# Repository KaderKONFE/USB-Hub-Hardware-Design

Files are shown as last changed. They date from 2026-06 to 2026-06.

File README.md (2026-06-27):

# USB Hub Hardware & PCB Design

This repository contains the schematic and PCB design for a high-speed USB Hub, developed according to industrial design rules and signal integrity standards.

## Tech Stack & Tools
* **CAD Software:** KiCad
* **Design Type:** Schematic Capture & PCB Layout
* **Key Focus:** Signal integrity, power management, and protection circuits.

## Features
* Designed high-speed USB data lines with proper impedance matching.
* Integrated power management and circuit protection elements.

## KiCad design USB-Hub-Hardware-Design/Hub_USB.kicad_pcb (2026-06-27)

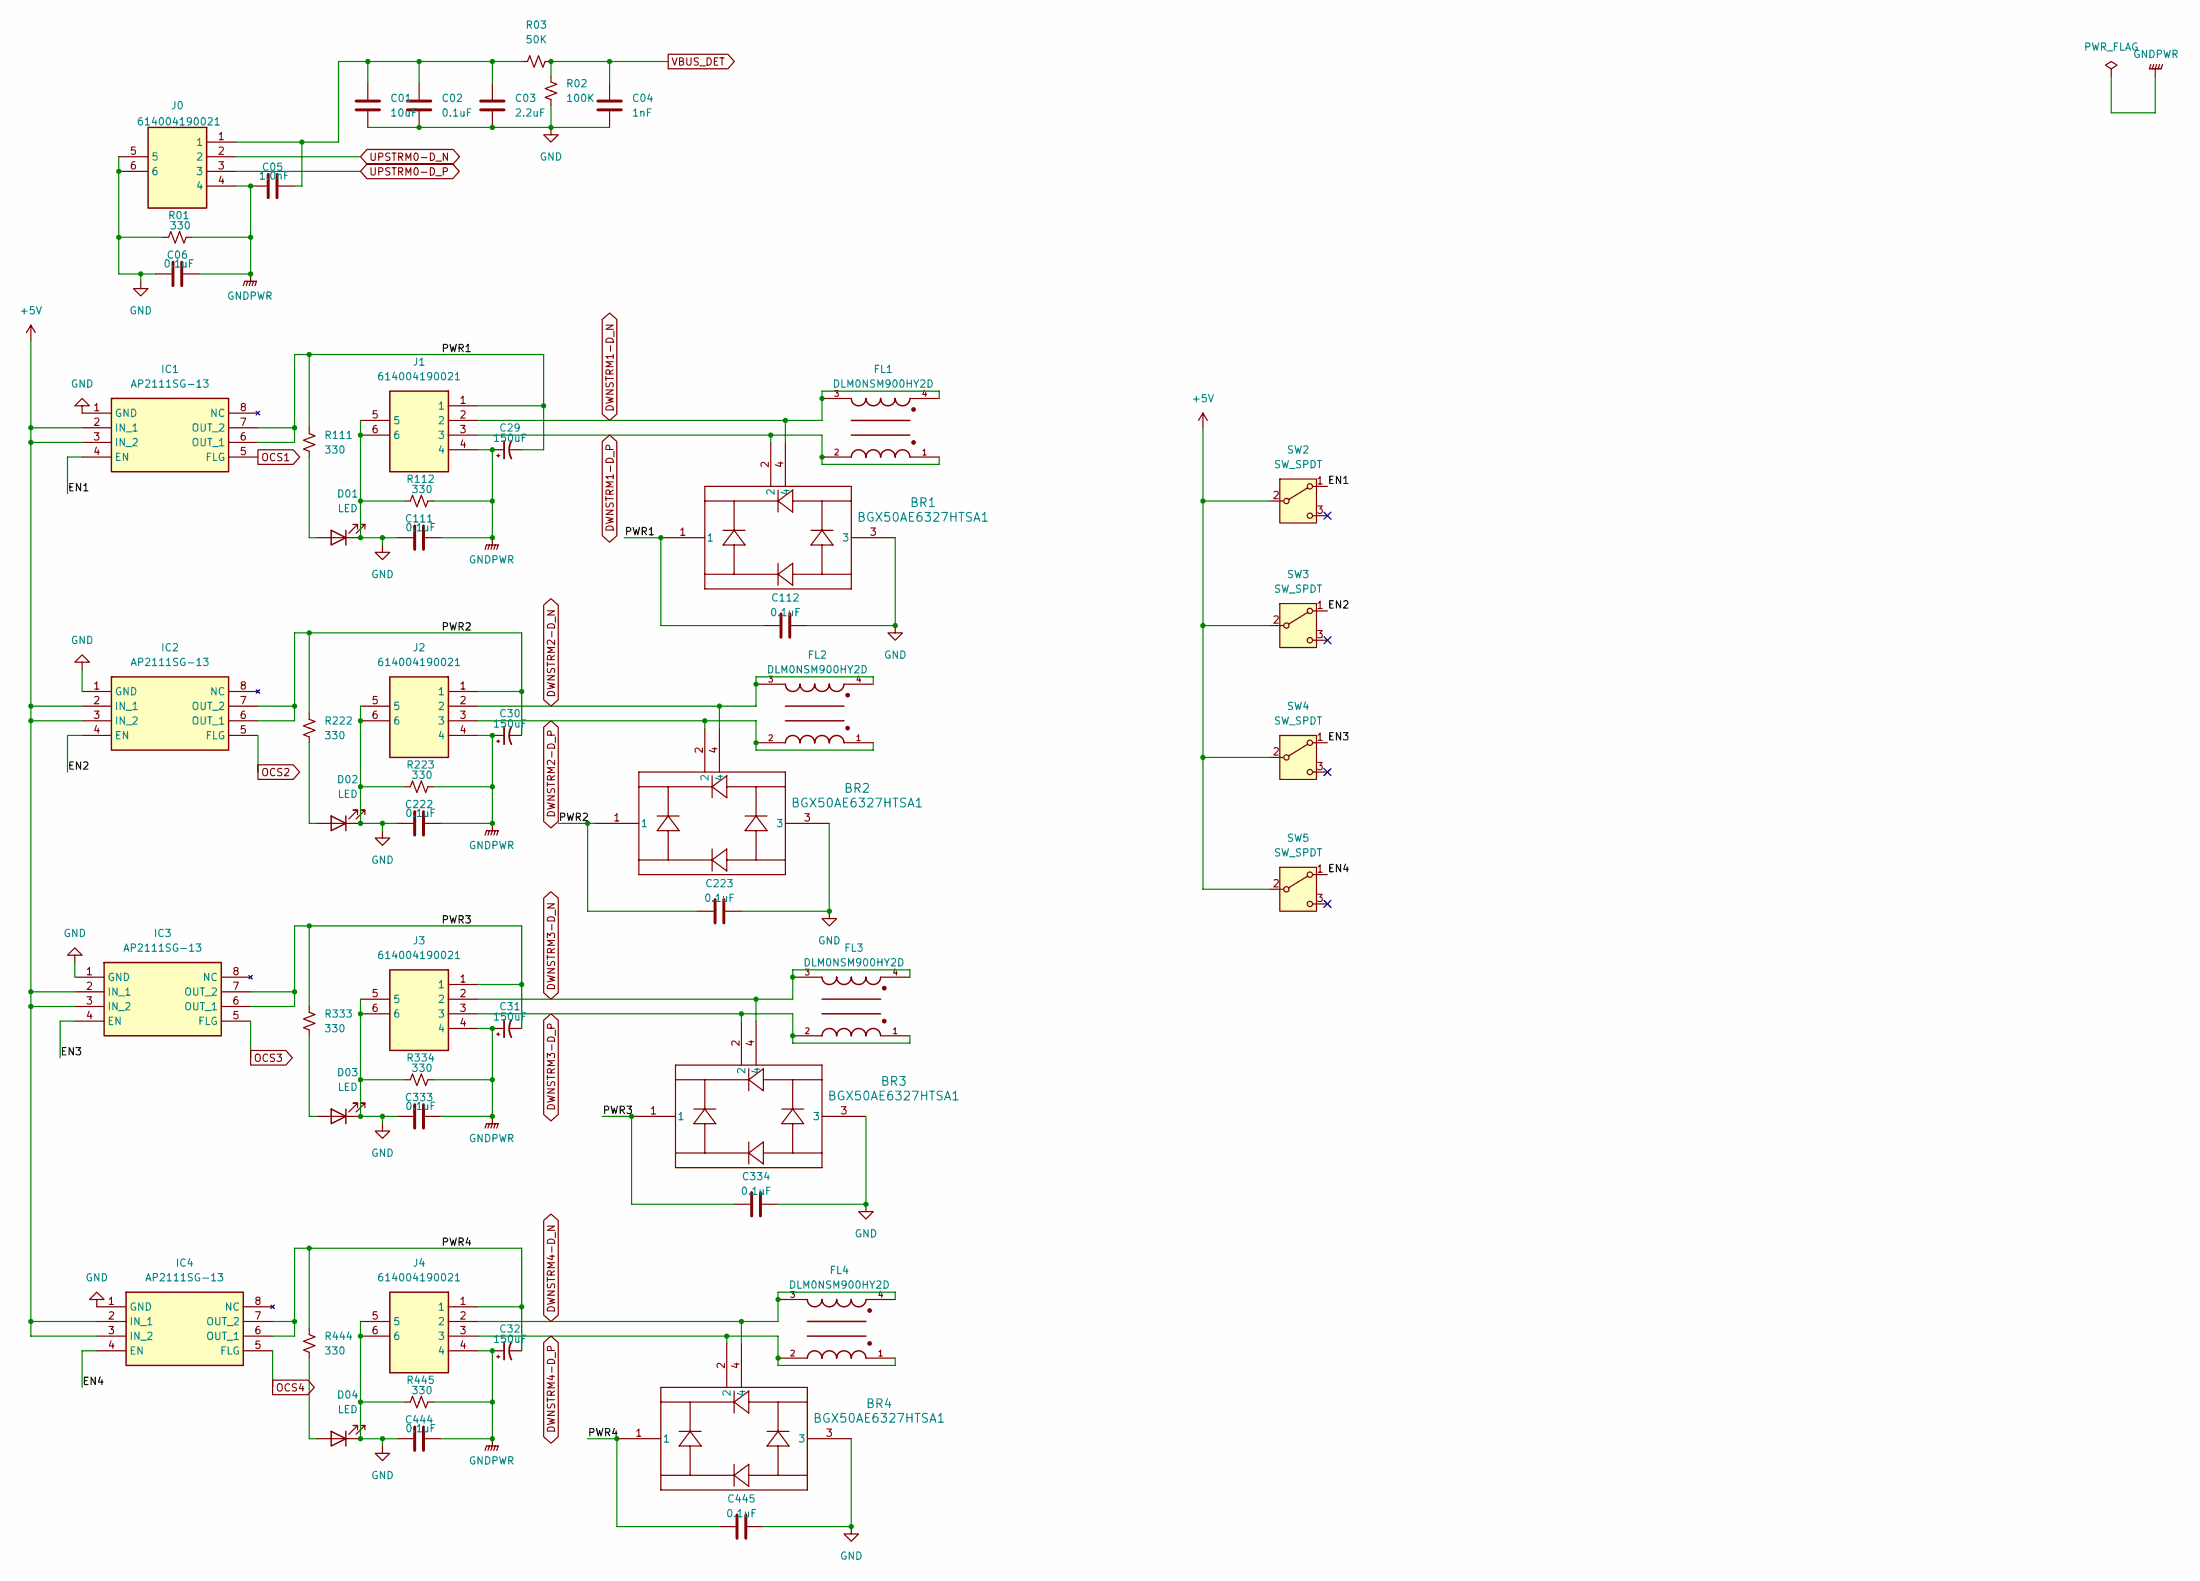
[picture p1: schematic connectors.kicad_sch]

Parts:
BR1, BR2, BR3, BR4: BGX50AE6327HTSA1
C01: 10uF; C_0603_1608Metric_Pad1.08x0.95mm_HandSolder
C02, C06, C111, C112, C222, C223, C333, C334, C444, C445: 0.1uF; C_0603_1608Metric_Pad1.08x0.95mm_HandSolder
C03: 2.2uF; C_0603_1608Metric_Pad1.08x0.95mm_HandSolder
C04: 1nF; C_0603_1608Metric_Pad1.08x0.95mm_HandSolder
C05: 1.0nF; C_0603_1608Metric_Pad1.08x0.95mm_HandSolder
C29, C30, C31, C32: 150uF; CP_Elec_5x5.7
D01, D02, D03, D04: LED; LED_0201_0603Metric_Pad0.64x0.40mm_HandSolder
FL1, FL2, FL3, FL4: DLM0NSM900HY2D; PARTREV N/A
IC1, IC2, IC3, IC4: AP2111SG-13; Manufacturer_Part_Number AP2111SG-13; Mouser Part Number 621-AP2111SG-13
J0, J1, J2, J3, J4: 614004190021; Manufacturer_Part_Number 614004190021; Mouser Part Number 710-614004190021
R01, R111, R112, R222, R223, R333, R334, R444, R445: 330; R_0603_1608Metric_Pad0.98x0.95mm_HandSolder
R02: 100K; R_0603_1608Metric_Pad0.98x0.95mm_HandSolder
R03: 50K; R_0603_1608Metric_Pad0.98x0.95mm_HandSolder
SW2, SW3, SW4, SW5: SW_SPDT; SW_SPDT_REED_MSDM-DT

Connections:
+5V: IC1.2 (IN_1), IC1.3 (IN_2), IC2.2 (IN_1), IC2.3 (IN_2), IC3.2 (IN_1), IC3.3 (IN_2), IC4.2 (IN_1), IC4.3 (IN_2), SW2.2 (B), SW3.2 (B), SW4.2 (B), SW5.2 (B); also elsewhere on the board
/Connectors/EN1: IC1.4 (EN), SW2.1 (A)
/Connectors/EN2: IC2.4 (EN), SW3.1 (A)
/Connectors/EN3: IC3.4 (EN), SW4.1 (A)
/Connectors/EN4: IC4.4 (EN), SW5.1 (A)
/Connectors/PWR1: BR1.1, C29.2, C112.2, IC1.6 (OUT_1), IC1.7 (OUT_2), J1.1, R111.1
/Connectors/PWR2: BR2.1, C30.2, C223.2, IC2.6 (OUT_1), IC2.7 (OUT_2), J2.1, R222.1
/Connectors/PWR3: BR3.1, C31.2, C334.2, IC3.6 (OUT_1), IC3.7 (OUT_2), J3.1, R333.1
/Connectors/PWR4: BR4.1, C32.2, C445.2, IC4.6 (OUT_1), IC4.7 (OUT_2), J4.1, R444.1
DWNSTRM1-D_N: BR1.4, FL1.3, FL1.4, J1.2; also elsewhere on the board
DWNSTRM1-D_P: BR1.2, FL1.1, FL1.2, J1.3; also elsewhere on the board
DWNSTRM2-D_N: BR2.4, FL2.3, FL2.4, J2.2; also elsewhere on the board
DWNSTRM2-D_P: BR2.2, FL2.1, FL2.2, J2.3; also elsewhere on the board
DWNSTRM3-D_N: BR3.4, FL3.3, FL3.4, J3.2; also elsewhere on the board
DWNSTRM3-D_P: BR3.2, FL3.1, FL3.2, J3.3; also elsewhere on the board
DWNSTRM4-D_N: BR4.4, FL4.3, FL4.4, J4.2; also elsewhere on the board
DWNSTRM4-D_P: BR4.2, FL4.1, FL4.2, J4.3; also elsewhere on the board
GND: BR1.3, BR2.3, BR3.3, BR4.3, C01.2, C02.2, C03.2, C04.2, C06.1, C111.1, C112.1, C222.1, C223.1, C333.1, C334.1, C444.1, C445.1, D01.1 (K), D02.1 (K), D03.1 (K), D04.1 (K), IC1.1 (GND), IC2.1 (GND), IC3.1 (GND), IC4.1 (GND), J0.5, J0.6, J1.5, J1.6, J2.5, J2.6, J3.5, J3.6, J4.5, J4.6, R01.1, R02.1, R112.1, R223.1, R334.1, R445.1; also elsewhere on the board
GNDPWR: C05.1, C06.2, C29.1, C30.1, C31.1, C32.1, C111.2, C222.2, C333.2, C444.2, J0.4, J1.4, J2.4, J3.4, J4.4, R01.2, R112.2, R223.2, R334.2, R445.2
unnamed: C01.1, C02.1, C03.1, C05.2, J0.1, R03.1
unnamed: D01.2 (A), R111.2
unnamed: D02.2 (A), R222.2
unnamed: D03.2 (A), R333.2
unnamed: D04.2 (A), R444.2
OCS1: IC1.5 (FLG); also elsewhere on the board
OCS2: IC2.5 (FLG); also elsewhere on the board
OCS3: IC3.5 (FLG); also elsewhere on the board
OCS4: IC4.5 (FLG); also elsewhere on the board
UPSTRM0-D_N: J0.2; also elsewhere on the board
UPSTRM0-D_P: J0.3; also elsewhere on the board
VBUS_DET: C04.1, R02.2, R03.2; also elsewhere on the board

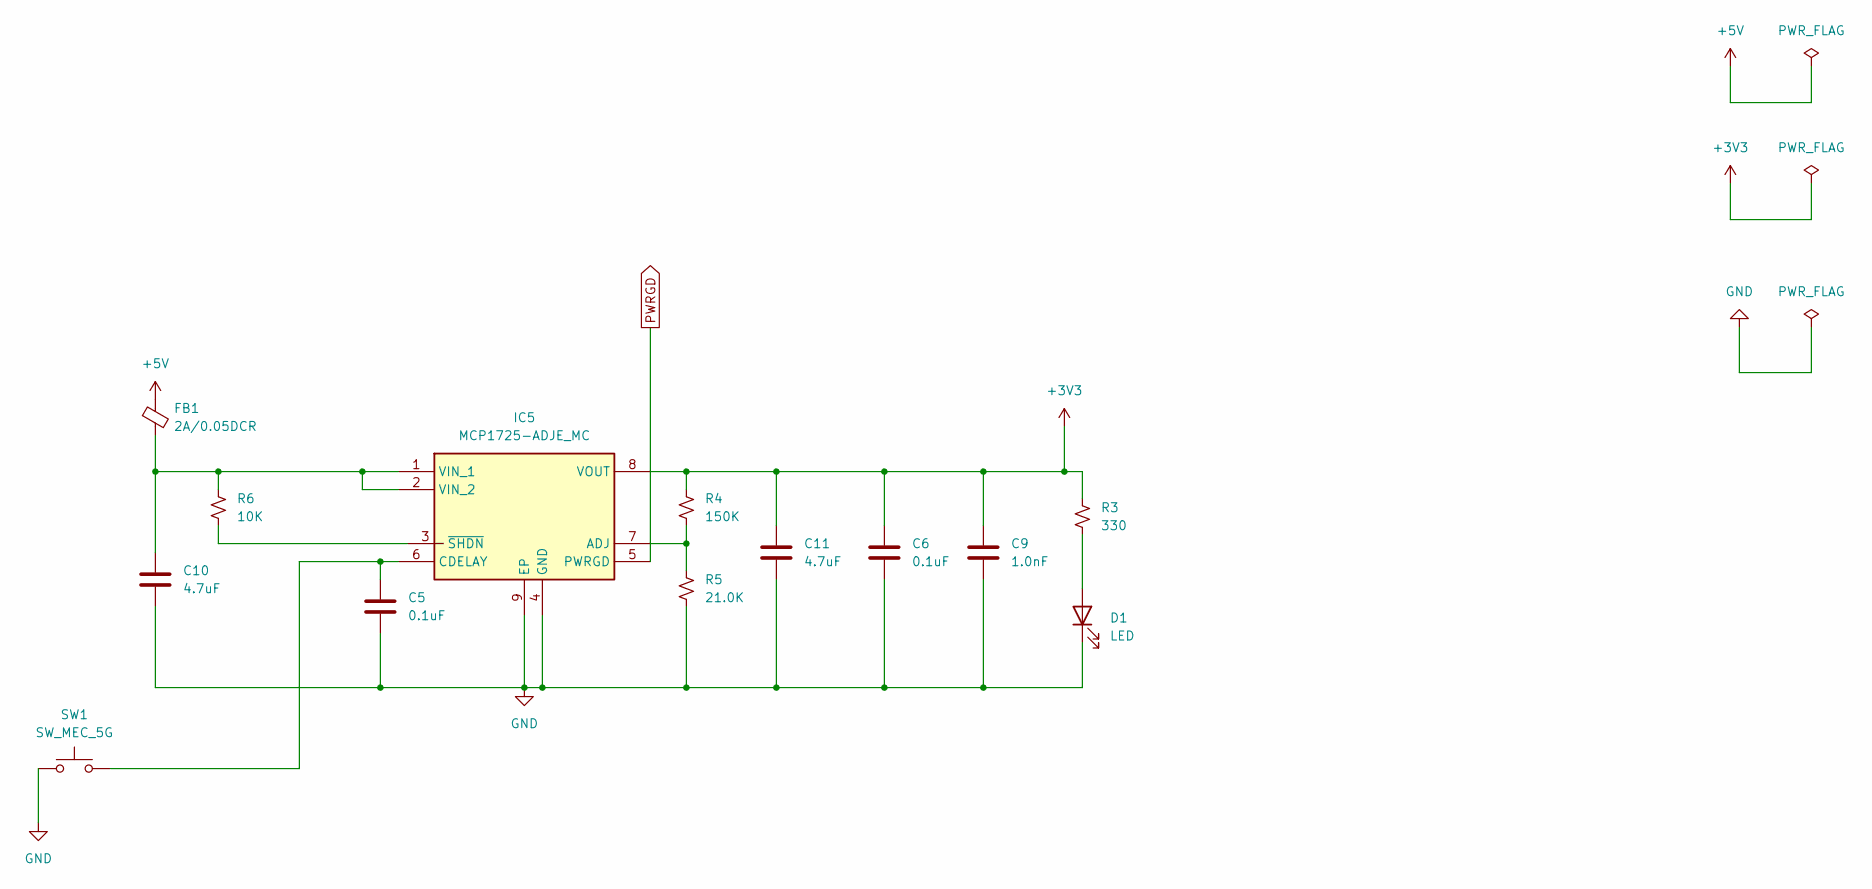
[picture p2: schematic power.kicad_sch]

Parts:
C5, C6: 0.1uF; C_0603_1608Metric_Pad1.08x0.95mm_HandSolder
C9: 1.0nF; C_0603_1608Metric_Pad1.08x0.95mm_HandSolder
C10, C11: 4.7uF; C_0603_1608Metric_Pad1.08x0.95mm_HandSolder
D1: LED; LED_0201_0603Metric_Pad0.64x0.40mm_HandSolder
FB1: 2A/0.05DCR; L_Vishay_IHSM-3825
IC5: MCP1725-ADJE_MC; Manufacturer_Part_Number MCP1725-ADJE/MC; Mouser Part Number 579-MCP1725-ADJE/MC
R3: 330; R_0603_1608Metric_Pad0.98x0.95mm_HandSolder
R4: 150K; R_0603_1608Metric_Pad0.98x0.95mm_HandSolder
R5: 21.0K; R_0603_1608Metric_Pad0.98x0.95mm_HandSolder
R6: 10K; R_0603_1608Metric_Pad0.98x0.95mm_HandSolder
SW1: SW_MEC_5G; SW_MEC_5GSH9

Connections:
+3V3: C6.1, C9.1, C11.1, IC5.8 (VOUT), R3.1, R4.1; also elsewhere on the board
+5V: FB1.1; also elsewhere on the board
GND: C5.2, C6.2, C9.2, C10.2, C11.2, D1.1 (K), IC5.4 (GND), IC5.9 (EP), R5.2, SW1.1 (A), SW1.2 (A); also elsewhere on the board
unnamed: D1.2 (A), R3.2
unnamed: IC5.7 (ADJ), R4.2, R5.1
unnamed: C5.1, IC5.6 (CDELAY), SW1.3 (B), SW1.4 (B)
unnamed: C10.1, FB1.2, IC5.1 (VIN_1), IC5.2 (VIN_2), R6.1
unnamed: IC5.3 (~SHDN), R6.2
PWRGD: IC5.5 (PWRGD); also elsewhere on the board

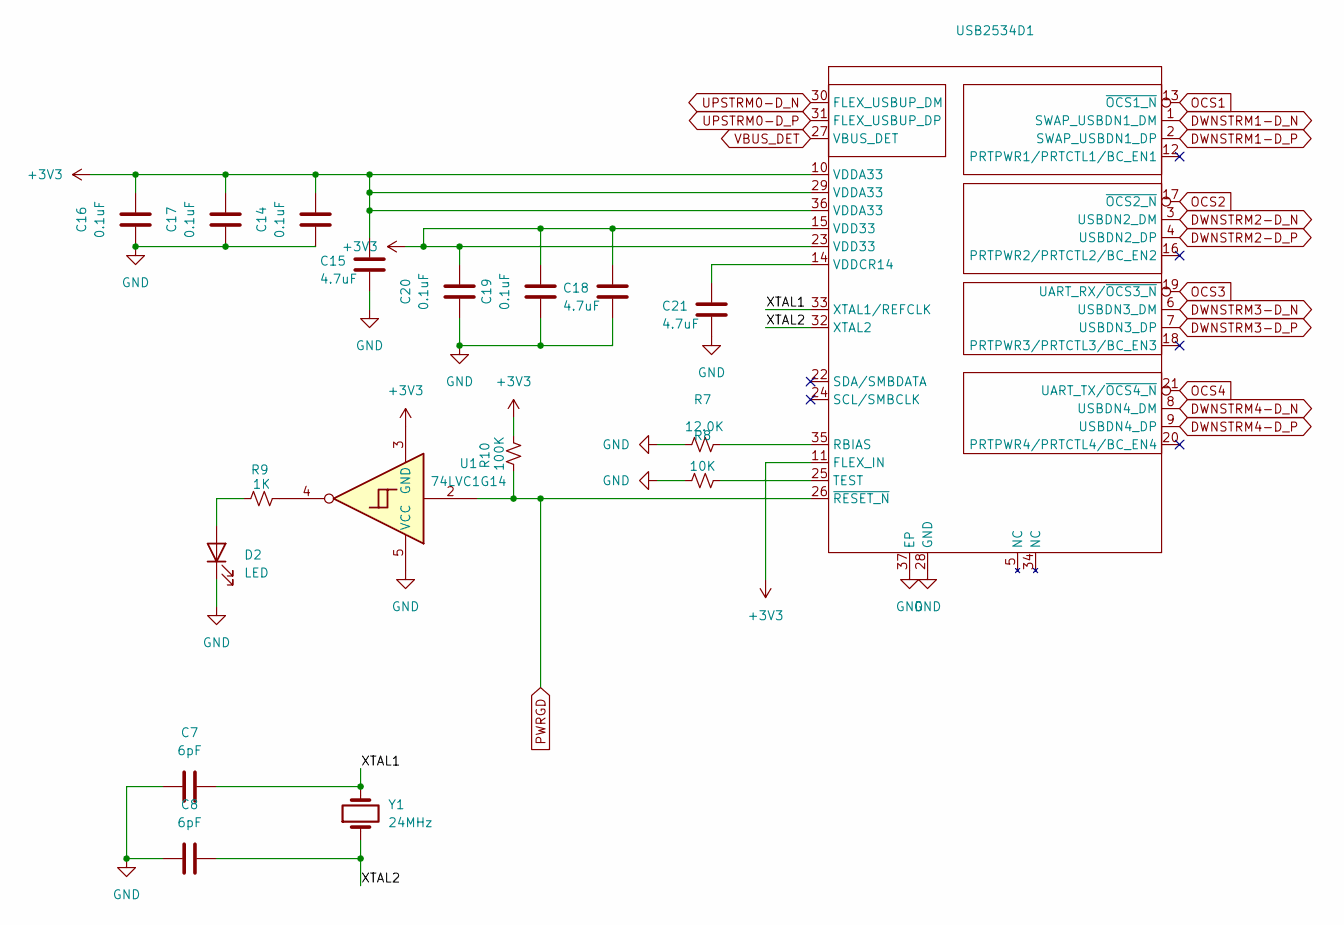
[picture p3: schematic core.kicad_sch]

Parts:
C7, C8: 6pF; C_0603_1608Metric_Pad1.08x0.95mm_HandSolder
C14, C16, C17, C19, C20: 0.1uF; C_0603_1608Metric_Pad1.08x0.95mm_HandSolder
C15, C18, C21: 4.7uF; C_0603_1608Metric_Pad1.08x0.95mm_HandSolder
D2: LED; LED_0201_0603Metric_Pad0.64x0.40mm_HandSolder
R7: 12.0K; R_0603_1608Metric_Pad0.98x0.95mm_HandSolder
R8: 10K; R_0603_1608Metric_Pad0.98x0.95mm_HandSolder
R9: 1K; R_0603_1608Metric_Pad0.98x0.95mm_HandSolder
R10: 100K; R_0603_1608Metric_Pad0.98x0.95mm_HandSolder
U1: 74LVC1G14; SOT-23-5
USB2534D1: QFN-36-1EP_6x6mm_P0.5mm_EP3.7x3.7mm
Y1: 24MHz; Crystal_SMD_ECS_CSM3X-2Pin_7.6x4.1mm

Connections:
+3V3: C14.2, C15.2, C16.2, C17.2, C18.2, C19.2, C20.2, R10.2, U1.3 (GND), USB2534D1.10 (VDDA33), USB2534D1.11 (FLEX_IN), USB2534D1.15 (VDD33), USB2534D1.23 (VDD33), USB2534D1.29 (VDDA33), USB2534D1.36 (VDDA33); also elsewhere on the board
/Core/XTAL1: C7.2, USB2534D1.33 (XTAL1/REFCLK), Y1.2
/Core/XTAL2: C8.2, USB2534D1.32 (XTAL2), Y1.1
DWNSTRM1-D_N: USB2534D1.1 (SWAP_USBDN1_DM); also elsewhere on the board
DWNSTRM1-D_P: USB2534D1.2 (SWAP_USBDN1_DP); also elsewhere on the board
DWNSTRM2-D_N: USB2534D1.3 (USBDN2_DM); also elsewhere on the board
DWNSTRM2-D_P: USB2534D1.4 (USBDN2_DP); also elsewhere on the board
DWNSTRM3-D_N: USB2534D1.6 (USBDN3_DM); also elsewhere on the board
DWNSTRM3-D_P: USB2534D1.7 (USBDN3_DP); also elsewhere on the board
DWNSTRM4-D_N: USB2534D1.8 (USBDN4_DM); also elsewhere on the board
DWNSTRM4-D_P: USB2534D1.9 (USBDN4_DP); also elsewhere on the board
GND: C7.1, C8.1, C14.1, C15.1, C16.1, C17.1, C18.1, C19.1, C20.1, C21.1, D2.1 (K), R7.1, R8.1, U1.5 (VCC), USB2534D1.28 (GND), USB2534D1.37 (EP); also elsewhere on the board
unnamed: D2.2 (A), R9.1
unnamed: R9.2, U1.4
unnamed: R7.2, USB2534D1.35 (RBIAS)
unnamed: R8.2, USB2534D1.25 (TEST)
unnamed: C21.2, USB2534D1.14 (VDDCR14)
OCS1: USB2534D1.13 (~OCS1_N); also elsewhere on the board
OCS2: USB2534D1.17 (~OCS2_N); also elsewhere on the board
OCS3: USB2534D1.19 (UART_RX/~OCS3_N); also elsewhere on the board
OCS4: USB2534D1.21 (UART_TX/~OCS4_N); also elsewhere on the board
PWRGD: R10.1, U1.2, USB2534D1.26 (~RESET_N); also elsewhere on the board
UPSTRM0-D_N: USB2534D1.30 (FLEX_USBUP_DM); also elsewhere on the board
UPSTRM0-D_P: USB2534D1.31 (FLEX_USBUP_DP); also elsewhere on the board
VBUS_DET: USB2534D1.27 (VBUS_DET); also elsewhere on the board

Board: 2 copper layers, 85 parts (0 on the bottom side), 45 nets, no tracks yet.
